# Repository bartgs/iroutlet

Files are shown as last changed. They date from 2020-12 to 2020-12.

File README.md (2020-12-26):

IrOutlet is an 8 port IR controlled power outlet.

A PIC16F15325 decodes the IR signal coming from a TSOP4836 IR receiver and steers a relay to switch on/off a power 
outlet port when an IR code is recognized.

IR codes:

1) Address: 0b00101 (Marantz)
2) Commands:
	- 0b00000000: switch all ports on
	- 0b00000001: switch port 1 on
	- 0b00000010: switch port 2 on
	- 0b00000011: switch port 3 on
	- 0b00000100: switch port 4 on
	- 0b00000101: switch port 5 on
	- 0b00000110: switch port 6 on
	- 0b00000111: switch port 7 on
	- 0b00001000: switch port 8 on
	- 0b00001001: switch all ports off
	- 0b00100000: switch port 1 off
	- 0b00100001: switch port 2 off
	- 0b00110010: switch port 3 off
	- 0b00110101: switch port 4 off
	- 0b00110100: switch port 5 off
	- 0b00110110: switch port 6 off
	- 0b00101001: switch port 7 off
	- 0b00111110: switch port 8 off

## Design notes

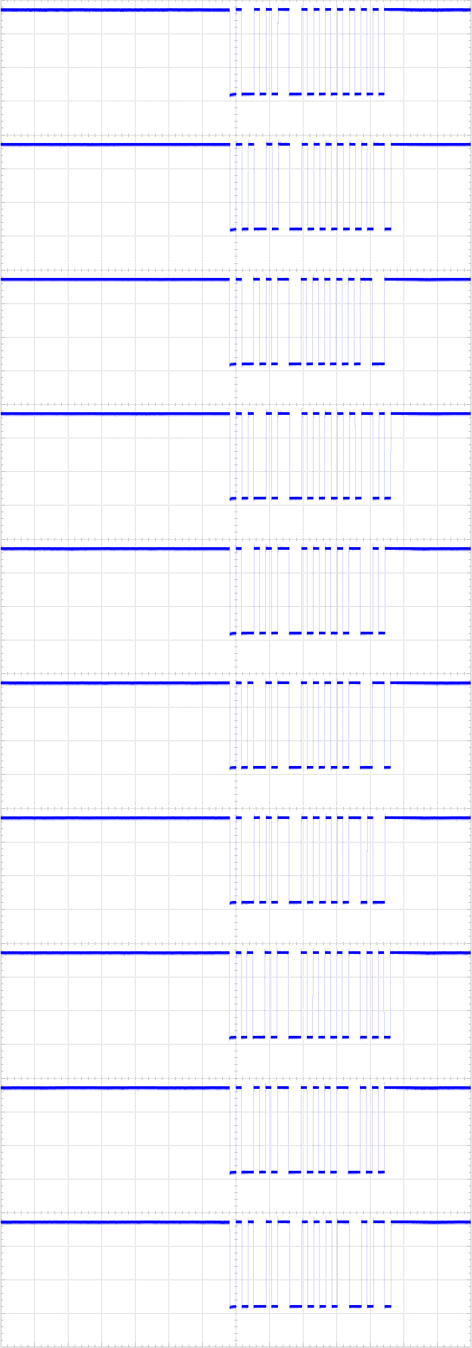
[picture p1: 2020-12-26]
Mplab/IrOutlet.X/doc/numpads.png

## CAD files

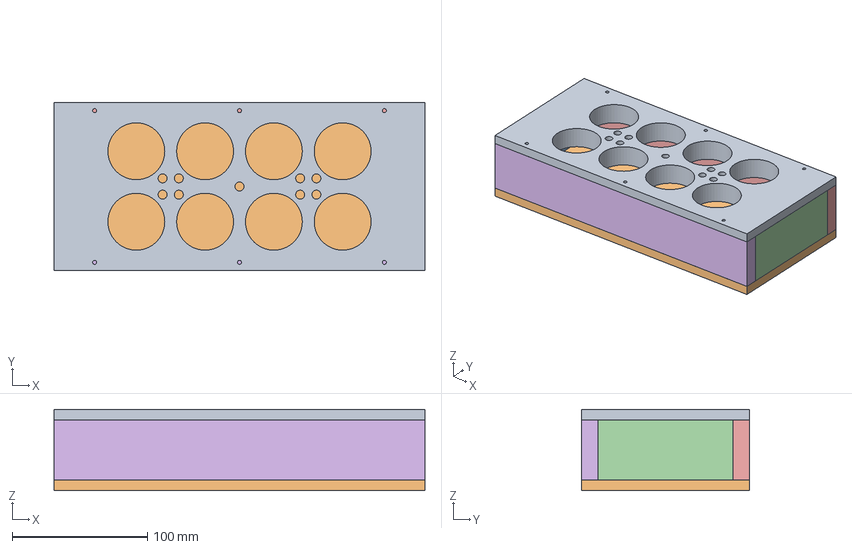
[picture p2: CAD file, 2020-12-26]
Freecad/IrOutlet.FCStd
274.0 x 124.0 x 60.0 mm
top.body
bottom.body
left.body
right.body
front.body
rear.body

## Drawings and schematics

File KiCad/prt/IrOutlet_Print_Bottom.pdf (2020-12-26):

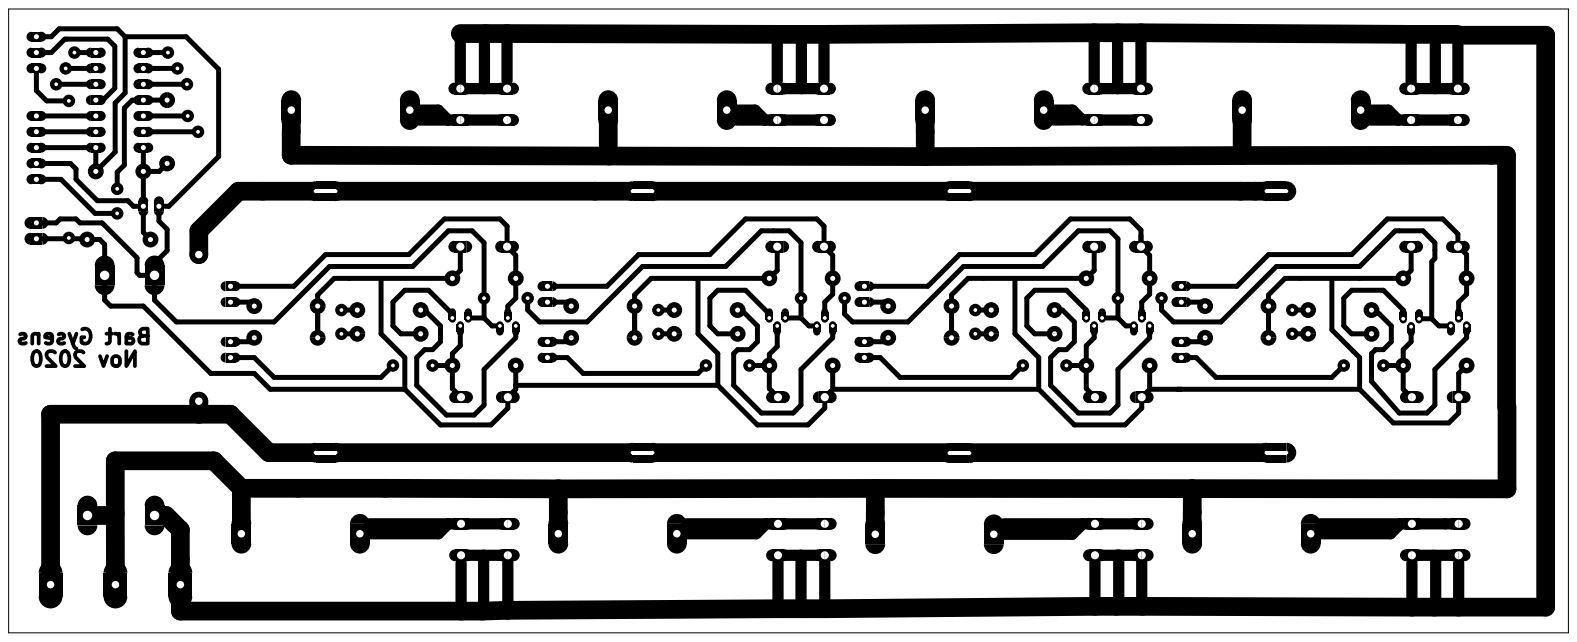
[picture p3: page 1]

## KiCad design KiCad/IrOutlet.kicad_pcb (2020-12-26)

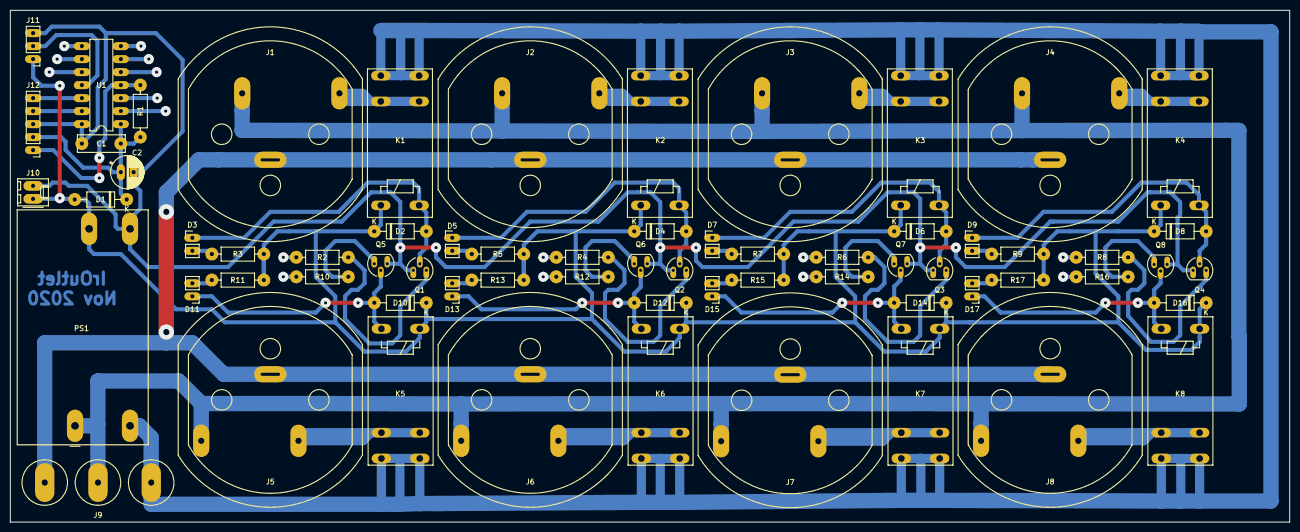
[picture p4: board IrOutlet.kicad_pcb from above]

Board: 2 copper layers, 250.0 x 100.0 mm, 66 parts (0 on the bottom side), 50 nets.

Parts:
C1: 100nF; C_L7.62mm_W3.2mm
C2: 100uF; CAP_6.3mm_P2.50mm
D1: 1N5819; DIODE_H
D2, D4, D6, D8, D10, D12, D14, D16: 1N4007; DIODE_H
D3, D5, D7, D9, D11, D13, D15, D17: RED; HDR_1x2
J1, J2, J3, J4, J5, J6, J7, J8: OUT; OUTLET
J9: 230 VAC; TB_1x3
J10: 5V; TB_1x2
J11: IrJack; HDR_1x3
J12: ICSP; HDR_1x5
K1, K2, K3, K4, K5, K6, K7, K8: RTD34005; RELAY_TE_RTD3405
PS1: IRM-05-5
Q1, Q2, Q3, Q4, Q5, Q6, Q7, Q8: KSC1008CY; TO-92
R1: 100k; RES_H
R2, R3, R4, R5, R6, R7, R8, R9, R10, R11, R12, R13, R14, R15, R16, R17: 1K; RES_H
U1: PIC16F15325; DIP-14

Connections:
/IrController/CLK: J12.5, U1.12
/IrController/DAT: J12.4, U1.13
/IrController/IR: J11.2, U1.11
/IrController/MCLR: J12.1, R1.2, U1.4
/PowerSupply/L1: J9.1, K1.3, K2.3, K3.3, K4.3, K5.3, K6.3, K7.3, K8.3, PS1.2
/PowerSupply/L2: J1.2, J2.2, J3.2, J4.2, J5.1, J6.1, J7.1, J8.1, J9.2, PS1.1
/PowerSupply/N: J1.3, J2.3, J3.3, J4.3, J5.3, J6.3, J7.3, J8.3, J9.3
/RelaisDriver1.1/EN: R2.2, U1.10
/RelaisDriver1.2/EN: R4.2, U1.9
/RelaisDriver1.3/EN: R6.2, U1.8
/RelaisDriver1.4/EN: R8.2, U1.7
/RelaisDriver2.1/EN: R10.2, U1.6
/RelaisDriver2.2/EN: R12.2, U1.5
/RelaisDriver2.3/EN: R16.2, U1.2
/RelaisDriver2.4/EN: R14.2, U1.3
GND: C1.2, C2.2, J10.2, J11.3, J12.3, PS1.3, Q1.1, Q2.1, Q3.1, Q4.1, Q5.1, Q6.1, Q7.1, Q8.1, U1.14
unnamed: D2.2, D3.1, K1.5, Q1.2
unnamed: D3.2, R3.1
unnamed: D4.2, D5.1, K2.5, Q2.2
unnamed: D5.2, R5.1
unnamed: D6.2, D7.1, K3.5, Q3.2
unnamed: D7.2, R7.1
unnamed: D8.2, D9.1, K4.5, Q4.2
unnamed: D9.2, R9.1
unnamed: D10.2, D11.1, K5.5, Q5.2
unnamed: D11.2, R11.1
unnamed: D12.2, D13.1, K6.5, Q6.2
unnamed: D13.2, R13.1
unnamed: D14.2, D15.1, K7.5, Q7.2
unnamed: D15.2, R15.1
unnamed: D16.2, D17.1, K8.5, Q8.2
unnamed: D17.2, R17.1
unnamed: J1.1, K1.2
unnamed: J2.1, K2.2
unnamed: J3.1, K3.2
unnamed: J4.1, K4.2
unnamed: J5.2, K5.2
unnamed: J6.2, K6.2
unnamed: J7.2, K7.2
unnamed: J8.2, K8.2
unnamed: Q1.3, R2.1
unnamed: Q2.3, R4.1
unnamed: Q3.3, R6.1
unnamed: Q4.3, R8.1
unnamed: Q5.3, R10.1
unnamed: Q6.3, R12.1
unnamed: Q7.3, R14.1
unnamed: Q8.3, R16.1
VCC: D1.2, D2.1, D4.1, D6.1, D8.1, D10.1, D12.1, D14.1, D16.1, J10.1, J11.1, K1.1, K2.1, K3.1, K4.1, K5.1, K6.1, K7.1, K8.1, PS1.4, R3.2, R5.2, R7.2, R9.2, R11.2, R13.2, R15.2, R17.2
VDD: C1.1, C2.1, D1.1, J12.2, R1.1, U1.1

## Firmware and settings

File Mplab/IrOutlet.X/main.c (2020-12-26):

/**
 *
 *  @file   main.c
 *  @date   18-12-2020
 *  @author Bart Gysens
 *
 *  @brief  Main entry point.
 *
 */

/* --------------------------- *
 * Project and system includes *
 * --------------------------- */
#include <xc.h>
#include <stdbool.h>
#include "rc5.h"

/* ------------------------------ *
 * PIC16F15325 Configuration bits *
 * ------------------------------ */

/*-- CONFIG1 --*/
#pragma config FEXTOSC = OFF    // External Oscillator mode selection bits (Oscillator not enabled)
#pragma config RSTOSC = HFINT32 // Power-up default value for COSC bits (HFINTOSC with OSCFRQ= 32 MHz and CDIV = 1:1)
#pragma config CLKOUTEN = OFF   // Clock Out Enable bit (CLKOUT function is disabled; i/o or oscillator function on OSC2)
#pragma config CSWEN = OFF      // Clock Switch Enable bit (The NOSC and NDIV bits cannot be changed by user software)
#pragma config FCMEN = OFF      // Fail-Safe Clock Monitor Enable bit (FSCM timer disabled)

/*-- CONFIG2 --*/
#pragma config MCLRE = ON       // Master Clear Enable bit (MCLR pin is Master Clear function)
#pragma config PWRTE = OFF      // Power-up Timer Enable bit (PWRT disabled)
#pragma config LPBOREN = OFF    // Low-Power BOR enable bit (ULPBOR disabled)
#pragma config BOREN = OFF      // Brown-out reset enable bits (Brown-out reset disabled)
#pragma config BORV = LO        // Brown-out Reset Voltage Selection (Brown-out Reset Voltage (VBOR) set to 1.9V on LF, and 2.45V on F Devices)
#pragma config ZCD = OFF        // Zero-cross detect disable (Zero-cross detect circuit is disabled at POR.)
#pragma config PPS1WAY = OFF    // Peripheral Pin Select one-way control (The PPSLOCK bit can be set and cleared repeatedly by software)
#pragma config STVREN = ON      // Stack Overflow/Underflow Reset Enable bit (Stack Overflow or Underflow will cause a reset)

/*-- CONFIG3 --*/
#pragma config WDTCPS = WDTCPS_31// WDT Period Select bits (Divider ratio 1:65536; software control of WDTPS)
#pragma config WDTE = OFF       // WDT operating mode (WDT Disabled, SWDTEN is ignored)
#pragma config WDTCWS = WDTCWS_7// WDT Window Select bits (window always open (100%); software control; keyed access not required)
#pragma config WDTCCS = SC      // WDT input clock selector (Software Control)

/*-- CONFIG4 --*/
#pragma config BBSIZE = BB512   // Boot Block Size Selection bits (512 words boot block size)
#pragma config BBEN = OFF       // Boot Block Enable bit (Boot Block disabled)
#pragma config SAFEN = OFF      // SAF Enable bit (SAF disabled)
#pragma config WRTAPP = OFF     // Application Block Write Protection bit (Application Block not write protected)
#pragma config WRTB = OFF       // Boot Block Write Protection bit (Boot Block not write protected)
#pragma config WRTC = OFF       // Configuration Register Write Protection bit (Configuration Register not write protected)
#pragma config WRTSAF = OFF     // Storage Area Flash Write Protection bit (SAF not write protected)
#pragma config LVP = OFF        // Low Voltage Programming Enable bit (High Voltage on MCLR/Vpp must be used for programming)

/*-- CONFIG5 --*/
#pragma config CP = OFF         // UserNVM Program memory code protection bit (UserNVM code protection disabled)


/* -------------------- *
 * Forward declarations *
 * -------------------- */
void _initialize(void);
void _execute(void);



/**
 *
 *  Main entry point.
 *
 */
void main(void)
{
    /*-- initialize i/o and peripherals --*/
    _initialize();

    /*-- execute application --*/
    _execute();
}



/**
 *
 *  Initialize ports, peripherals & interrupts for the project.
 *
 */
void _initialize(void)
{
    di();
    
    /*-- disable conflicting peripherals --*/
    PMD4bits.UART1MD = 1;   /* EUSART1 disabled */
    PMD4bits.UART2MD = 1;   /* EUSART2 disabled */
    PMD4bits.MSSP1MD = 1;   /* MSSP1 disabled */    
    
    /*-- initialize IO pins --*/
    PORTA &= 0b11001111;     /* reset pin value */
    LATA &= 0b11001111;      /* reset pin latch */
    ANSELA &= 0b11001111;    /* set as digital io */    
    ODCONA &= 0b11001111;    /* enable push-pull */
    SLRCONA &= 0b11001111;   /* disable rate limit */
    TRISA &= 0b11001111;     /* set as digital output pin */  
    
    PORTC &= 0b11000000;     /* reset pin value */
    LATC &= 0b11000000;      /* reset pin latch */
    ANSELC &= 0b11000000;    /* set as digital io */
    ODCONC &= 0b11000000;    /* enable push-pull */
    SLRCONC &= 0b11000000;   /* disable rate limit */
    TRISC &= 0b11000000;     /* set as digital output pin */
    
    rc5Setup();
    
    ei();
}



/**
 *
 *  Execute application.
 *
 */
void _execute(void)
{
    RC5_COMMAND rc5Command;    

    /*-- enter forever loop --*/
    for(;; NOP())
    {        
        if ( rc5Ready() == true )
        {
            /*-- cache data --*/
            di();                   /* disable interrupts */
            rc5Command = rc5Get();  /* store local copy of data */
            rc5Clear();             /* clear ready flag */            
            ei();                   /* enable interrupts */

            /*-- check if address is VCR1 (0b00101) (Medion MD83709: device VCR, brand marantz [code 0257]) --*/
            if (rc5Command.address == 0b00101 )
            {
                switch ( rc5Command.command )
                {
                    case 0b0000000: /* '0 */
                    {
                        /*-- switch all outlets on --*/
                        PORTC |= 0b00111111;
                        PORTA |= 0b00110000;                        
                        break;
                    }

                    case 0b0000001: /* '1' */
                    {
                        /*-- switch outlet 1 on --*/
                        PORTCbits.RC0 = 1;                        
                        break;
                    }

                    case 0b0000010: /* '2' */
                    {
                        /*-- swith outlet 2 on --*/
                        PORTCbits.RC1 = 1;
                        break;
                    }

                    case 0b0000011: /* '3' */
                    {
                        /*-- switch outlet 3 on --*/
                        PORTCbits.RC2 = 1;
                        break;
                    }

                    case 0b0000100: /* '4' */
                    {
                        /*-- switch outlet 4 on --*/
                        PORTCbits.RC3 = 1;
                        break;
                    }

                    case 0b0000101: /* '5' */
                    {
                        /*-- switch outlet 5 on --*/
                        PORTCbits.RC4 = 1;
                        break;
                    }
                    
                    case 0b0000110: /* '6' */
                    {
                        /*-- switch outlet 6 on --*/
                        PORTCbits.RC5 = 1;
                        break;
                    }

                    case 0b0000111: /* '7' */
                    {
                        /*-- switch outlet 7 on --*/
                        PORTAbits.RA4 = 1;
                        break;
                    }

                    case 0b0001000: /* '8' */
                    {
                        /*-- switch outlet 8 on --*/
                        PORTAbits.RA5 = 1;
                        break;
                    }

                    case 0b0001001: /* '9' */
                    {
                        /*-- switch all outlets off --*/
                        PORTC &= 0b11000000;
                        PORTA &= 0b11001111;
                        break;
                    }
                    
                    case 0b00100000: /* 'PGM+' */
                    {
                        /*-- switch outlet 1 off --*/
                        PORTCbits.RC0 = 0;
                        break;
                    }

                    case 0b00100001: /* 'PGM-' */
                    {
                        /*-- switch outlet 2 off --*/
                        PORTCbits.RC1 = 0;
                        break;
                    }
                    
                    case 0b00110010: /* '<<' */
                    {
                        /*-- switch outlet 3 off --*/
                        PORTCbits.RC2 = 0;
                        break;
                    }

                    case 0b00110101: /* '>' */
                    {
                        /*-- switch outlet 4 off --*/
                        PORTCbits.RC3 = 0;
                        break;
                    }

                    case 0b00110100: /* '>>' */
                    {
                        /*-- switch outlet 5 off --*/
                        PORTCbits.RC4 = 0;
                        break;
                    }

                    case 0b00110110: /* '[]' */
                    {
                        /*-- switch outlet 6 off --*/
                        PORTCbits.RC5 = 0;
                        break;
                    }

                    case 0b00101001: /* '||' */
                    {
                        /*-- switch outlet 7 off --*/
                        PORTAbits.RA4 = 0;
                        break;
                    }

                    case 0b00111110: /* 'AV' */
                    {
                        /*-- switch outlet 8 off --*/
                        PORTAbits.RA5 = 0;
                        break;
                    }

                    default:
                    {
                        /*-- do nothing --*/
                        break;
                    }
                }                                
            }                        
        }
    }
}

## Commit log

2020-12-26 KiCad library cleanup
2020-12-26 Added KiCad footprints + fixed library references in schematic
    [IrController.sch, IrOutlet.kicad_pcb]
2020-12-27 KiCad schematic: changed documentation links relative to project folder.
    [IrController.sch, PowerSupply.sch, RelaisDriver1.sch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]
